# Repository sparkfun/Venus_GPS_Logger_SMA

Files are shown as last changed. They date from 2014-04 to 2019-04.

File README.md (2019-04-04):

**NOTE:** *This product has been retired from our catalog. If you are looking for more up-to-date info, please check out some of these resources to see how other users are still hacking and improving on this product.*
* *[SparkFun Forum](https://forum.sparkfun.com/)*
* *[Comments Here on GitHub](https://github.com/sparkfun/Venus_GPS_Logger_SMA/issues)*
* *[IRC Channel](https://www.sparkfun.com/news/263)*

SparkFun Venus GPS Logger - SMA Connector
=========================================

SparkFun Venus GPS Logger - SMA Connector

[*SparkFun Venus GPS Logger - SMA Connector (GPS-10920)*](https://www.sparkfun.com/products/10920)

This is a breakout board for the Venus638FLPx chip. It can be configured up to 20Hz update rate. This has an on-board JST connector for battery
power and an SMA connector for an antenna. This unit supports external SPI flash memory data logging, and has the 32M Serial Flash Memory IC.

Repository Contents
-------------------
* **/Hardware** - All Eagle design files (.brd, .sch)
* **/Production** - Test bed files and production panel files

Documentation
--------------
* **[SparkFun Fritzing repo](https://github.com/sparkfun/Fritzing_Parts)** - Fritzing diagrams for SparkFun products.
* **[SparkFun 3D Model repo](https://github.com/sparkfun/3D_Models)** - 3D models of SparkFun products. 

License Information
-------------------

This product is _**open source**_! 

Please review the LICENSE.md file for license information. 

If you have any questions or concerns on licensing, please contact techsupport@sparkfun.com.

Distributed as-is; no warranty is given.

- Your friends at SparkFun.

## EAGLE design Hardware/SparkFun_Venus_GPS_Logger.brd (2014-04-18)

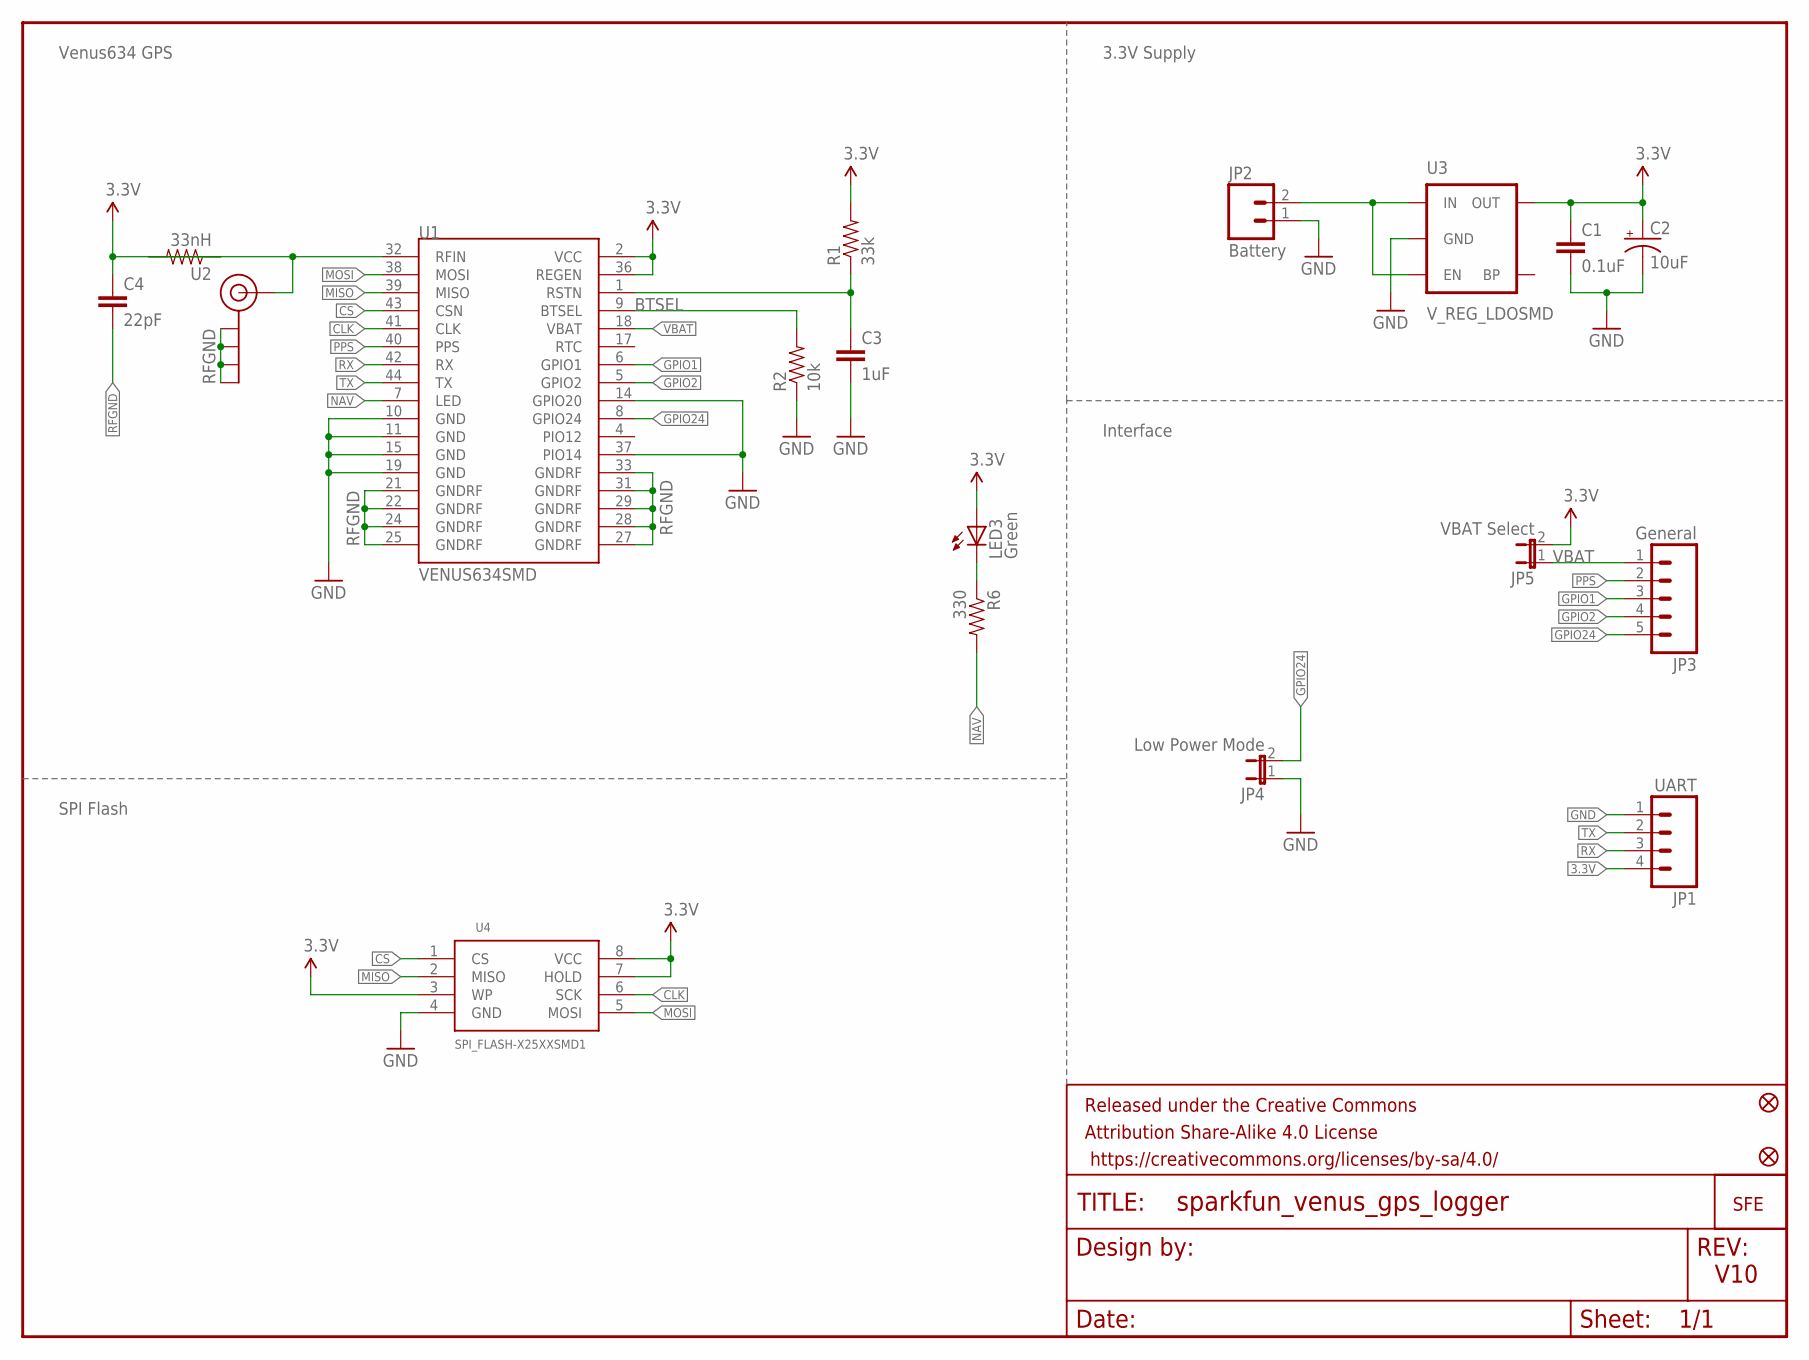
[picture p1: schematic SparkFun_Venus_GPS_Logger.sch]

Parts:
C1: 0.1uF; 0603-CAP
C2: 10uF; EIA3216
C3: 1uF; 0603-CAP
C4: 22pF; 0603-CAP
FID1, FID2: FIDUCIAL1X2; FIDUCIAL-1X2
FRAME1: FRAME-LETTER; CREATIVE_COMMONS
J$1: SMA_EDGE; SMA-EDGE
JP1: UART; 1X04
JP2: Battery; S2B-PH
JP3: General; 1X05
JP4: Low Power Mode; SJ_2S
JP5: VBAT Select; SJ_2S
LED3: Green; LED-0603
R1: 33k; 0603-RES
R2: 10k; 0603-RES
R6: 330; 0603-RES
U1: VENUS634SMD; LGA44
U2: 33nH; 0603-RES
U3: V_REG_LDOSMD; SOT23-5
U4: SPI_FLASH-X25XXSMD1; SO08-EIAJ
U$1: LOGO-SFESK; SFE-LOGO-FLAME

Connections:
3.3V: C1.1, C2.A (+), C4.1, JP1.4, JP5.2, LED3.A, R1.2, U1.2 (VCC), U1.36 (REGEN), U2.1, U3.5 (OUT), U4.3 (WP), U4.7 (HOLD), U4.8 (VCC)
BTSEL: R2.2, U1.9 (BTSEL)
CLK: U1.41 (CLK), U4.6 (SCK)
CS: U1.43 (CSN), U4.1 (CS)
GND: C1.2, C2.C (-), C3.2, JP1.1, JP2.1, JP4.1, R2.1, U1.10 (GND), U1.11 (GND), U1.14 (GPIO20), U1.15 (GND), U1.19 (GND), U1.37 (PIO14), U3.2 (GND), U4.4 (GND)
GPIO1: JP3.3, U1.6 (GPIO1)
GPIO2: JP3.4, U1.5 (GPIO2)
GPIO24: JP3.5, JP4.2, U1.8 (GPIO24)
MISO: U1.39 (MISO), U4.2 (MISO)
MOSI: U1.38 (MOSI), U4.5 (MOSI)
unnamed: LED3.C, R6.1
unnamed: C3.1, R1.1, U1.1 (RSTN)
unnamed: J$1.SIG (SIGNAL), U1.32 (RFIN), U2.2
NAV: R6.2, U1.7 (LED)
PPS: JP3.2, U1.40 (PPS)
RFGND: C4.2, J$1.GND@0 (GND), J$1.GND@1 (GND), J$1.GND@2 (GND), J$1.GND@3 (GND), U1.21 (GNDRF), U1.22 (GNDRF), U1.24 (GNDRF), U1.25 (GNDRF), U1.27 (GNDRF), U1.28 (GNDRF), U1.29 (GNDRF), U1.31 (GNDRF), U1.33 (GNDRF)
RX: JP1.3, U1.42 (RX)
TX: JP1.2, U1.44 (TX)
VBAT: JP3.1, JP5.1, U1.18 (VBAT)
VBATT: JP2.2, U3.1 (IN), U3.3 (EN)

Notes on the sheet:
SPI Flash
Venus634 GPS
3.3V Supply
Interface
V10

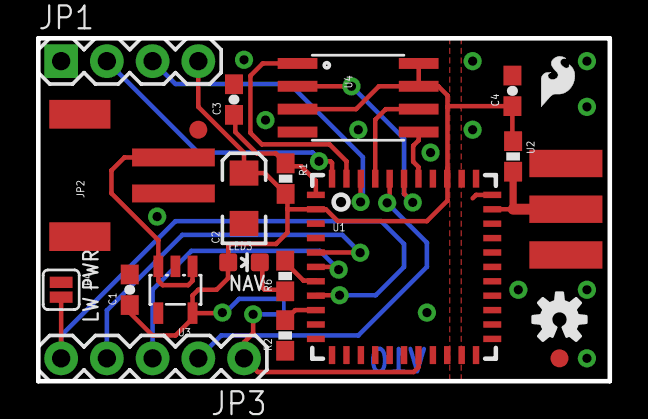
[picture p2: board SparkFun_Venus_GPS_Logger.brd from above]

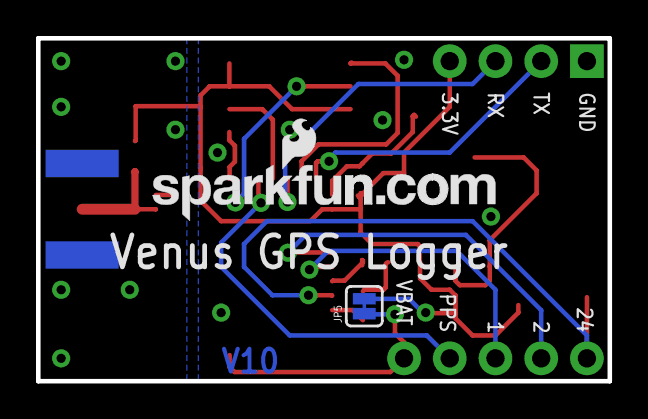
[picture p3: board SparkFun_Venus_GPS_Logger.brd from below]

Board: 2 copper layers, 31.8 x 19.1 mm, 24 parts (2 on the bottom side), 20 nets.

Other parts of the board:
U$2: OSHW-LOGO-S
U$3: SFE-NEW-WEBLOGO

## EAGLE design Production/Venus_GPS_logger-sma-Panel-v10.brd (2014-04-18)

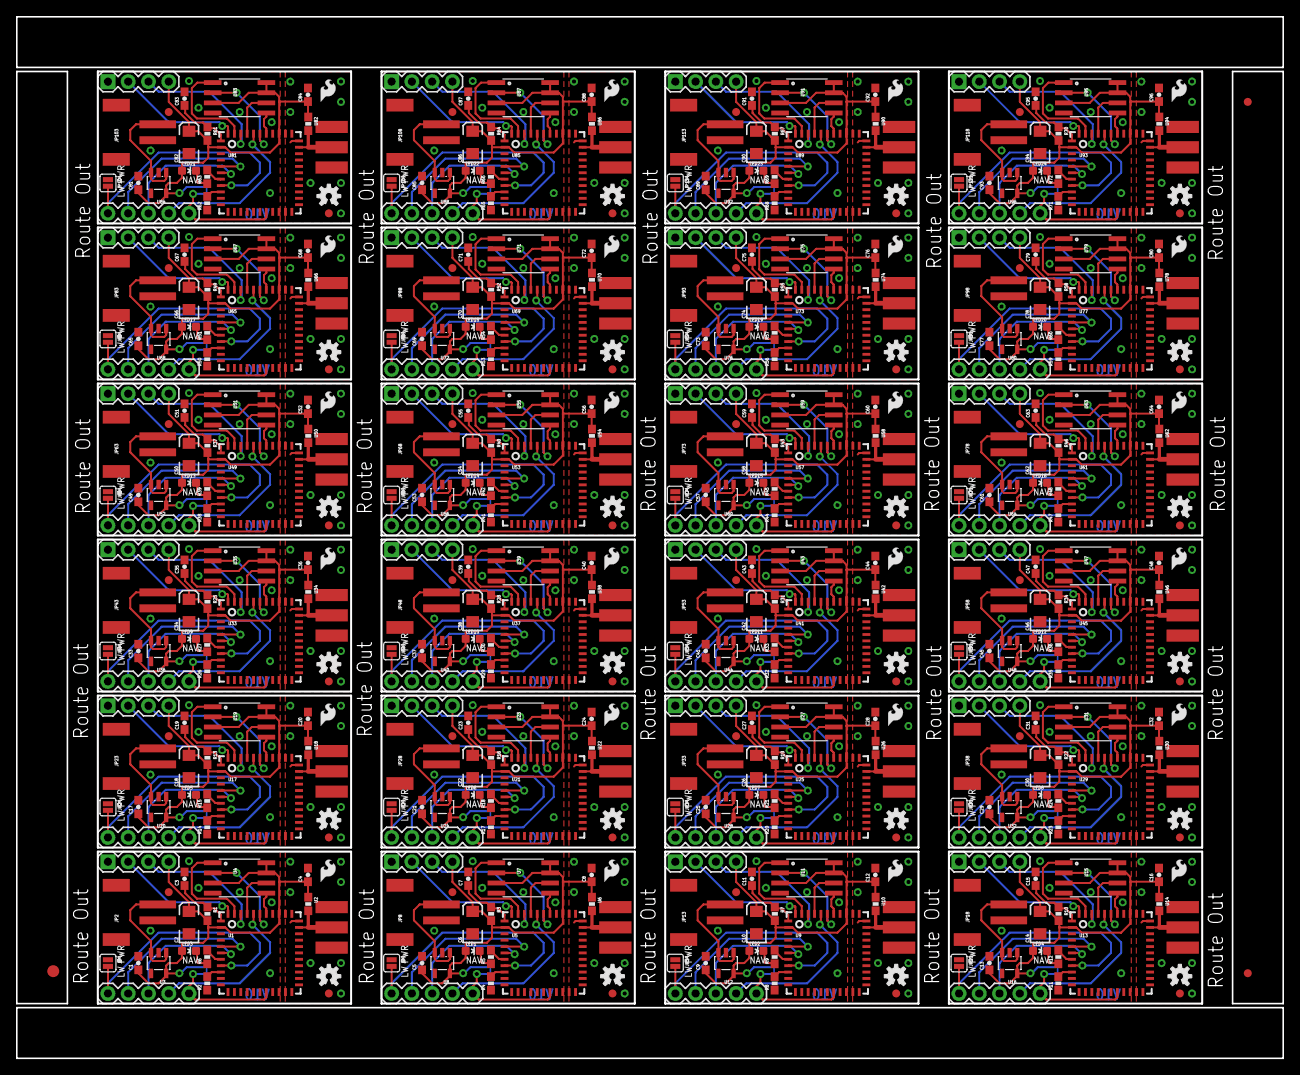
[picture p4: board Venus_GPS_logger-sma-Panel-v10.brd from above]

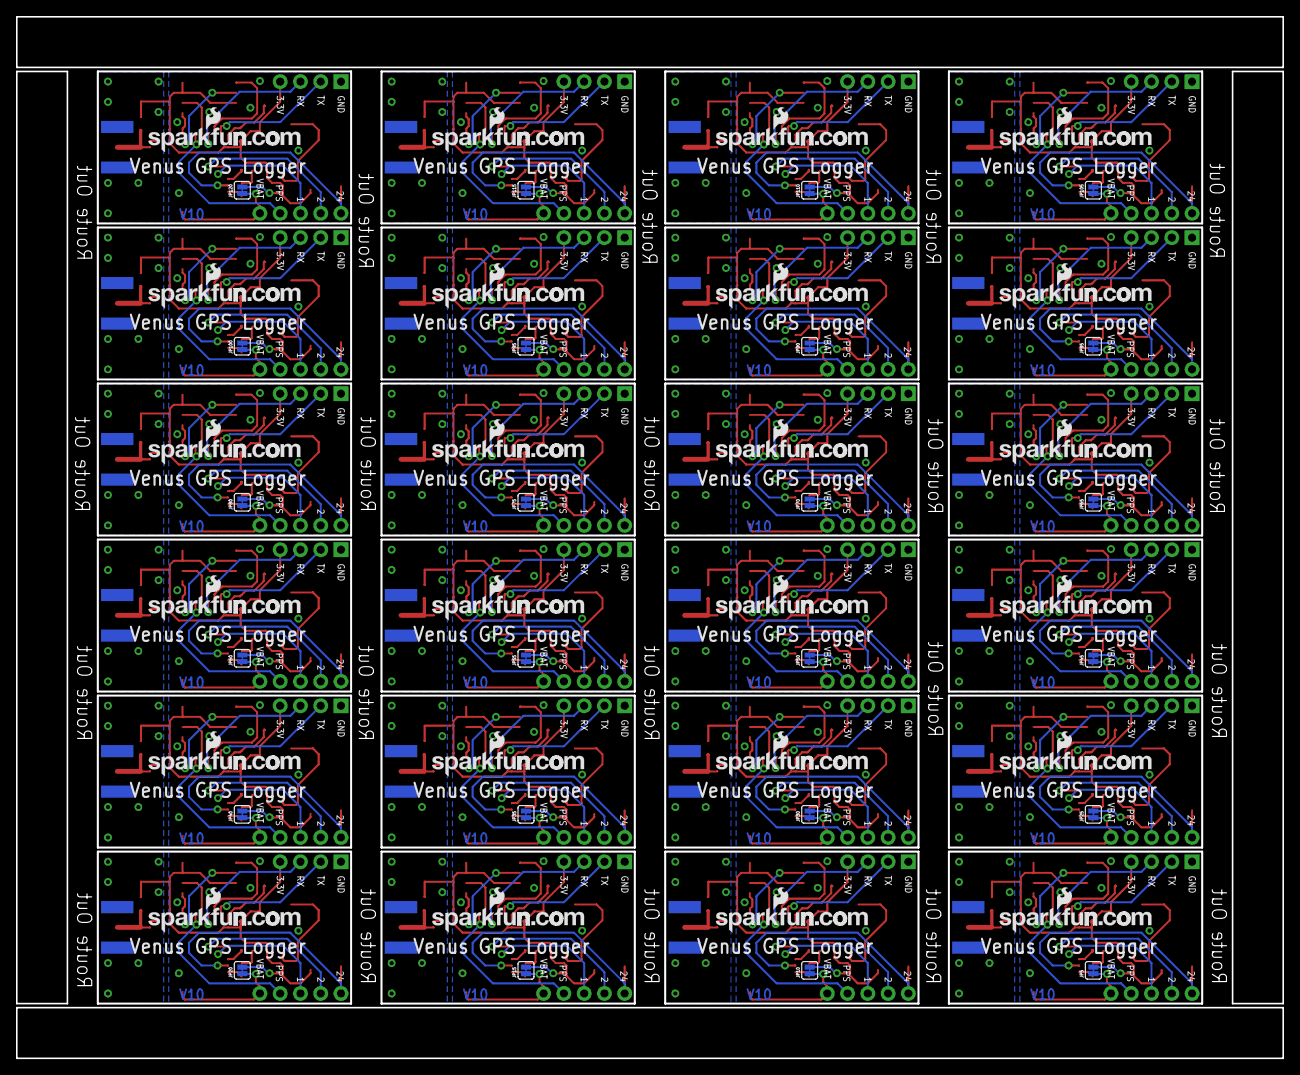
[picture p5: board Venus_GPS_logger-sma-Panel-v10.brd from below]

Board: 2 copper layers, 158.8 x 130.6 mm, 555 parts (48 on the bottom side), 480 nets.

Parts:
C1, C5, C9, C13, C17, C21, C25, C29, C33, C37, C41, C45, C49, C53, C57, C61, C65, C69, C73, C77, C81, C85, C89, C93: 0.1uF; 0603-CAP
C2, C6, C10, C14, C18, C22, C26, C30, C34, C38, C42, C46, C50, C54, C58, C62, C66, C70, C74, C78, C82, C86, C90, C94: 10uF; EIA3216
C3, C7, C11, C15, C19, C23, C27, C31, C35, C39, C43, C47, C51, C55, C59, C63, C67, C71, C75, C79, C83, C87, C91, C95: 1uF; 0603-CAP
C4, C8, C12, C16, C20, C24, C28, C32, C36, C40, C44, C48, C52, C56, C60, C64, C68, C72, C76, C80, C84, C88, C92, C96: 22pF; 0603-CAP
E$1: FIDUCIAL-1.5X3
E$3, E$4: FIDUCIAL-1X2
FID1, FID2, FID3, FID4, FID5, FID6, FID7, FID8, FID9, FID10, FID11, FID12, FID13, FID14, FID15, FID16, FID17, FID18, FID19, FID20, FID21, FID22, FID23, FID24, FID25, FID26, FID27, FID28, FID29, FID30, FID31, FID32, FID33, FID34, FID35, FID36, FID37, FID38, FID39, FID40, FID41, FID42, FID43, FID44, FID45, FID46, FID47, FID48: FIDUCIAL1X2; FIDUCIAL-1X2
J$1, J$2, J$3, J$4, J$5, J$6, J$7, J$8, J$9, J$10, J$11, J$12, J$13, J$14, J$15, J$16, J$17, J$18, J$19, J$20, J$21, J$22, J$23, J$24: SMA_EDGE; SMA-EDGE
JP1, JP6, JP11, JP16, JP21, JP26, JP31, JP36, JP41, JP46, JP51, JP56, JP61, JP66, JP71, JP76, JP81, JP86, JP91, JP96, JP101, JP106, JP111, JP116: UART; 1X04
JP2, JP8, JP13, JP18, JP23, JP28, JP33, JP38, JP43, JP48, JP53, JP58, JP63, JP68, JP73, JP78, JP83, JP88, JP93, JP98, JP103, JP108, JP113, JP118: Battery; S2B-PH
JP3, JP7, JP12, JP17, JP22, JP27, JP32, JP37, JP42, JP47, JP52, JP57, JP62, JP67, JP72, JP77, JP82, JP87, JP92, JP97, JP102, JP107, JP112, JP117: General; 1X05
JP4, JP9, JP14, JP19, JP24, JP29, JP34, JP39, JP44, JP49, JP54, JP59, JP64, JP69, JP74, JP79, JP84, JP89, JP94, JP99, JP104, JP109, JP114, JP119: Low Power Mode; SJ_2S
JP5, JP10, JP15, JP20, JP25, JP30, JP35, JP40, JP45, JP50, JP55, JP60, JP65, JP70, JP75, JP80, JP85, JP90, JP95, JP100, JP105, JP110, JP115, JP120: VBAT Select; SJ_2S
LED1, LED2, LED3, LED4, LED5, LED6, LED7, LED8, LED9, LED10, LED11, LED12, LED13, LED14, LED15, LED16, LED17, LED18, LED19, LED20, LED21, LED22, LED23, LED24: Green; LED-0603
R1, R3, R7, R10, R13, R16, R19, R22, R25, R28, R31, R34, R37, R40, R43, R46, R49, R52, R55, R58, R61, R64, R67, R70: 33k; 0603-RES
R2, R4, R8, R11, R14, R17, R20, R23, R26, R29, R32, R35, R38, R41, R44, R47, R50, R53, R56, R59, R62, R65, R68, R71: 10k; 0603-RES
R5, R6, R9, R12, R15, R18, R21, R24, R27, R30, R33, R36, R39, R42, R45, R48, R51, R54, R57, R60, R63, R66, R69, R72: 330; 0603-RES
U1, U5, U9, U13, U17, U21, U25, U29, U33, U37, U41, U45, U49, U53, U57, U61, U65, U69, U73, U77, U81, U85, U89, U93: VENUS634SMD; LGA44
U2, U6, U10, U14, U18, U22, U26, U30, U34, U38, U42, U46, U50, U54, U58, U62, U66, U70, U74, U78, U82, U86, U90, U94: 33nH; 0603-RES
U3, U8, U12, U16, U20, U24, U28, U32, U36, U40, U44, U48, U52, U56, U60, U64, U68, U72, U76, U80, U84, U88, U92, U96: V_REG_LDOSMD; SOT23-5
U4, U7, U11, U15, U19, U23, U27, U31, U35, U39, U43, U47, U51, U55, U59, U63, U67, U71, U75, U79, U83, U87, U91, U95: SPI_FLASH-X25XXSMD1; SO08-EIAJ
U$1, U$4, U$7, U$10, U$13, U$16, U$19, U$22, U$25, U$28, U$31, U$34, U$37, U$40, U$43, U$46, U$49, U$52, U$55, U$58, U$61, U$64, U$67, U$70: LOGO-SFESK; SFE-LOGO-FLAME
U$2, U$5, U$8, U$11, U$14, U$17, U$20, U$23, U$26, U$29, U$32, U$35, U$38, U$41, U$44, U$47, U$50, U$53, U$56, U$59, U$62, U$65, U$68, U$71: OSHW-LOGO-S
U$3, U$6, U$9, U$12, U$15, U$18, U$21, U$24, U$27, U$30, U$33, U$36, U$39, U$42, U$45, U$48, U$51, U$54, U$57, U$60, U$63, U$66, U$69, U$72: SFE-NEW-WEBLOGO

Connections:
3.3V: C1.1, C2.A, C4.1, JP1.4, JP5.2, LED3.A, R1.2, U1.2, U1.36, U2.1, U3.5, U4.3, U4.7, U4.8
3.3V1: C5.1, C6.A, C8.1, JP6.4, JP10.2, LED1.A, R3.2, U5.2, U5.36, U6.1, U7.3, U7.7, U7.8, U8.5
3.3V2: C9.1, C10.A, C12.1, JP11.4, JP15.2, LED2.A, R7.2, U9.2, U9.36, U10.1, U11.3, U11.7, U11.8, U12.5
3.3V3: C13.1, C14.A, C16.1, JP16.4, JP20.2, LED4.A, R10.2, U13.2, U13.36, U14.1, U15.3, U15.7, U15.8, U16.5
3.3V4: C17.1, C18.A, C20.1, JP21.4, JP25.2, LED5.A, R13.2, U17.2, U17.36, U18.1, U19.3, U19.7, U19.8, U20.5
3.3V5: C21.1, C22.A, C24.1, JP26.4, JP30.2, LED6.A, R16.2, U21.2, U21.36, U22.1, U23.3, U23.7, U23.8, U24.5
3.3V6: C25.1, C26.A, C28.1, JP31.4, JP35.2, LED7.A, R19.2, U25.2, U25.36, U26.1, U27.3, U27.7, U27.8, U28.5
3.3V7: C29.1, C30.A, C32.1, JP36.4, JP40.2, LED8.A, R22.2, U29.2, U29.36, U30.1, U31.3, U31.7, U31.8, U32.5
3.3V8: C33.1, C34.A, C36.1, JP41.4, JP45.2, LED9.A, R25.2, U33.2, U33.36, U34.1, U35.3, U35.7, U35.8, U36.5
3.3V9: C37.1, C38.A, C40.1, JP46.4, JP50.2, LED10.A, R28.2, U37.2, U37.36, U38.1, U39.3, U39.7, U39.8, U40.5
3.3V10: C41.1, C42.A, C44.1, JP51.4, JP55.2, LED11.A, R31.2, U41.2, U41.36, U42.1, U43.3, U43.7, U43.8, U44.5
3.3V11: C45.1, C46.A, C48.1, JP56.4, JP60.2, LED12.A, R34.2, U45.2, U45.36, U46.1, U47.3, U47.7, U47.8, U48.5
3.3V12: C49.1, C50.A, C52.1, JP61.4, JP65.2, LED13.A, R37.2, U49.2, U49.36, U50.1, U51.3, U51.7, U51.8, U52.5
3.3V13: C53.1, C54.A, C56.1, JP66.4, JP70.2, LED14.A, R40.2, U53.2, U53.36, U54.1, U55.3, U55.7, U55.8, U56.5
3.3V14: C57.1, C58.A, C60.1, JP71.4, JP75.2, LED15.A, R43.2, U57.2, U57.36, U58.1, U59.3, U59.7, U59.8, U60.5
3.3V15: C61.1, C62.A, C64.1, JP76.4, JP80.2, LED16.A, R46.2, U61.2, U61.36, U62.1, U63.3, U63.7, U63.8, U64.5
3.3V16: C65.1, C66.A, C68.1, JP81.4, JP85.2, LED17.A, R49.2, U65.2, U65.36, U66.1, U67.3, U67.7, U67.8, U68.5
3.3V17: C69.1, C70.A, C72.1, JP86.4, JP90.2, LED18.A, R52.2, U69.2, U69.36, U70.1, U71.3, U71.7, U71.8, U72.5
3.3V18: C73.1, C74.A, C76.1, JP91.4, JP95.2, LED19.A, R55.2, U73.2, U73.36, U74.1, U75.3, U75.7, U75.8, U76.5
3.3V19: C77.1, C78.A, C80.1, JP96.4, JP100.2, LED20.A, R58.2, U77.2, U77.36, U78.1, U79.3, U79.7, U79.8, U80.5
3.3V20: C81.1, C82.A, C84.1, JP101.4, JP105.2, LED21.A, R61.2, U81.2, U81.36, U82.1, U83.3, U83.7, U83.8, U84.5
3.3V21: C85.1, C86.A, C88.1, JP106.4, JP110.2, LED22.A, R64.2, U85.2, U85.36, U86.1, U87.3, U87.7, U87.8, U88.5
3.3V22: C89.1, C90.A, C92.1, JP111.4, JP115.2, LED23.A, R67.2, U89.2, U89.36, U90.1, U91.3, U91.7, U91.8, U92.5
3.3V23: C93.1, C94.A, C96.1, JP116.4, JP120.2, LED24.A, R70.2, U93.2, U93.36, U94.1, U95.3, U95.7, U95.8, U96.5
BTSEL: R2.2, U1.9
BTSEL1: R4.2, U5.9
BTSEL2: R8.2, U9.9
BTSEL3: R11.2, U13.9
BTSEL4: R14.2, U17.9
BTSEL5: R17.2, U21.9
BTSEL6: R20.2, U25.9
BTSEL7: R23.2, U29.9
BTSEL8: R26.2, U33.9
BTSEL9: R29.2, U37.9
BTSEL10: R32.2, U41.9
BTSEL11: R35.2, U45.9
BTSEL12: R38.2, U49.9
BTSEL13: R41.2, U53.9
BTSEL14: R44.2, U57.9
BTSEL15: R47.2, U61.9
BTSEL16: R50.2, U65.9
BTSEL17: R53.2, U69.9
BTSEL18: R56.2, U73.9
BTSEL19: R59.2, U77.9
BTSEL20: R62.2, U81.9
BTSEL21: R65.2, U85.9
BTSEL22: R68.2, U89.9
BTSEL23: R71.2, U93.9
CLK: U1.41, U4.6
CLK1: U5.41, U7.6
CLK2: U9.41, U11.6
CLK3: U13.41, U15.6
CLK4: U17.41, U19.6
CLK5: U21.41, U23.6
CLK6: U25.41, U27.6
CLK7: U29.41, U31.6
CLK8: U33.41, U35.6
CLK9: U37.41, U39.6
CLK10: U41.41, U43.6
CLK11: U45.41, U47.6
CLK12: U49.41, U51.6
CLK13: U53.41, U55.6
CLK14: U57.41, U59.6
CLK15: U61.41, U63.6
CLK16: U65.41, U67.6
CLK17: U69.41, U71.6
CLK18: U73.41, U75.6
CLK19: U77.41, U79.6
CLK20: U81.41, U83.6
CLK21: U85.41, U87.6
CLK22: U89.41, U91.6
CLK23: U93.41, U95.6
CS: U1.43, U4.1
CS1: U5.43, U7.1
CS2: U9.43, U11.1
CS3: U13.43, U15.1
CS4: U17.43, U19.1
CS5: U21.43, U23.1
CS6: U25.43, U27.1
CS7: U29.43, U31.1
CS8: U33.43, U35.1
CS9: U37.43, U39.1
CS10: U41.43, U43.1
CS11: U45.43, U47.1
CS12: U49.43, U51.1
CS13: U53.43, U55.1
CS14: U57.43, U59.1
CS15: U61.43, U63.1
CS16: U65.43, U67.1
CS17: U69.43, U71.1
CS18: U73.43, U75.1
CS19: U77.43, U79.1
CS20: U81.43, U83.1
CS21: U85.43, U87.1
CS22: U89.43, U91.1
CS23: U93.43, U95.1
GND: C1.2, C2.C, C3.2, JP1.1, JP2.1, JP4.1, R2.1, U1.10, U1.11, U1.14, U1.15, U1.19, U1.37, U3.2, U4.4
GND1: C5.2, C6.C, C7.2, JP6.1, JP8.1, JP9.1, R4.1, U5.10, U5.11, U5.14, U5.15, U5.19, U5.37, U7.4, U8.2
GND2: C9.2, C10.C, C11.2, JP11.1, JP13.1, JP14.1, R8.1, U9.10, U9.11, U9.14, U9.15, U9.19, U9.37, U11.4, U12.2
GND3: C13.2, C14.C, C15.2, JP16.1, JP18.1, JP19.1, R11.1, U13.10, U13.11, U13.14, U13.15, U13.19, U13.37, U15.4, U16.2
GND4: C17.2, C18.C, C19.2, JP21.1, JP23.1, JP24.1, R14.1, U17.10, U17.11, U17.14, U17.15, U17.19, U17.37, U19.4, U20.2
GND5: C21.2, C22.C, C23.2, JP26.1, JP28.1, JP29.1, R17.1, U21.10, U21.11, U21.14, U21.15, U21.19, U21.37, U23.4, U24.2
GND6: C25.2, C26.C, C27.2, JP31.1, JP33.1, JP34.1, R20.1, U25.10, U25.11, U25.14, U25.15, U25.19, U25.37, U27.4, U28.2
GND7: C29.2, C30.C, C31.2, JP36.1, JP38.1, JP39.1, R23.1, U29.10, U29.11, U29.14, U29.15, U29.19, U29.37, U31.4, U32.2
GND8: C33.2, C34.C, C35.2, JP41.1, JP43.1, JP44.1, R26.1, U33.10, U33.11, U33.14, U33.15, U33.19, U33.37, U35.4, U36.2
GND9: C37.2, C38.C, C39.2, JP46.1, JP48.1, JP49.1, R29.1, U37.10, U37.11, U37.14, U37.15, U37.19, U37.37, U39.4, U40.2
GND10: C41.2, C42.C, C43.2, JP51.1, JP53.1, JP54.1, R32.1, U41.10, U41.11, U41.14, U41.15, U41.19, U41.37, U43.4, U44.2
GND11: C45.2, C46.C, C47.2, JP56.1, JP58.1, JP59.1, R35.1, U45.10, U45.11, U45.14, U45.15, U45.19, U45.37, U47.4, U48.2
GND12: C49.2, C50.C, C51.2, JP61.1, JP63.1, JP64.1, R38.1, U49.10, U49.11, U49.14, U49.15, U49.19, U49.37, U51.4, U52.2
GND13: C53.2, C54.C, C55.2, JP66.1, JP68.1, JP69.1, R41.1, U53.10, U53.11, U53.14, U53.15, U53.19, U53.37, U55.4, U56.2
GND14: C57.2, C58.C, C59.2, JP71.1, JP73.1, JP74.1, R44.1, U57.10, U57.11, U57.14, U57.15, U57.19, U57.37, U59.4, U60.2
GND15: C61.2, C62.C, C63.2, JP76.1, JP78.1, JP79.1, R47.1, U61.10, U61.11, U61.14, U61.15, U61.19, U61.37, U63.4, U64.2
GND16: C65.2, C66.C, C67.2, JP81.1, JP83.1, JP84.1, R50.1, U65.10, U65.11, U65.14, U65.15, U65.19, U65.37, U67.4, U68.2
GND17: C69.2, C70.C, C71.2, JP86.1, JP88.1, JP89.1, R53.1, U69.10, U69.11, U69.14, U69.15, U69.19, U69.37, U71.4, U72.2
GND18: C73.2, C74.C, C75.2, JP91.1, JP93.1, JP94.1, R56.1, U73.10, U73.11, U73.14, U73.15, U73.19, U73.37, U75.4, U76.2
GND19: C77.2, C78.C, C79.2, JP96.1, JP98.1, JP99.1, R59.1, U77.10, U77.11, U77.14, U77.15, U77.19, U77.37, U79.4, U80.2
GND20: C81.2, C82.C, C83.2, JP101.1, JP103.1, JP104.1, R62.1, U81.10, U81.11, U81.14, U81.15, U81.19, U81.37, U83.4, U84.2
GND21: C85.2, C86.C, C87.2, JP106.1, JP108.1, JP109.1, R65.1, U85.10, U85.11, U85.14, U85.15, U85.19, U85.37, U87.4, U88.2
GND22: C89.2, C90.C, C91.2, JP111.1, JP113.1, JP114.1, R68.1, U89.10, U89.11, U89.14, U89.15, U89.19, U89.37, U91.4, U92.2
GND23: C93.2, C94.C, C95.2, JP116.1, JP118.1, JP119.1, R71.1, U93.10, U93.11, U93.14, U93.15, U93.19, U93.37, U95.4, U96.2
GPIO1: JP3.3, U1.6
GPIO2: JP3.4, U1.5
GPIO3: JP7.3, U5.6
GPIO4: JP7.4, U5.5
GPIO5: JP7.5, JP9.2, U5.8
GPIO6: JP12.3, U9.6
GPIO7: JP12.4, U9.5
GPIO8: JP12.5, JP14.2, U9.8
GPIO9: JP17.3, U13.6
GPIO10: JP17.4, U13.5
GPIO11: JP17.5, JP19.2, U13.8
GPIO12: JP22.3, U17.6
GPIO13: JP22.4, U17.5
GPIO14: JP22.5, JP24.2, U17.8
GPIO15: JP27.3, U21.6
GPIO16: JP27.4, U21.5
GPIO17: JP27.5, JP29.2, U21.8
GPIO18: JP32.3, U25.6
GPIO19: JP32.4, U25.5
GPIO20: JP32.5, JP34.2, U25.8
GPIO21: JP37.3, U29.6
GPIO22: JP37.4, U29.5
GPIO23: JP37.5, JP39.2, U29.8
GPIO24: JP3.5, JP4.2, U1.8
GPIO25: JP42.3, U33.6
GPIO26: JP42.4, U33.5
GPIO27: JP42.5, JP44.2, U33.8
GPIO28: JP47.3, U37.6
GPIO29: JP47.4, U37.5
GPIO30: JP47.5, JP49.2, U37.8
GPIO31: JP52.3, U41.6
GPIO32: JP52.4, U41.5
GPIO33: JP52.5, JP54.2, U41.8
GPIO34: JP57.3, U45.6
GPIO35: JP57.4, U45.5
GPIO36: JP57.5, JP59.2, U45.8
GPIO37: JP62.3, U49.6
GPIO38: JP62.4, U49.5
GPIO39: JP62.5, JP64.2, U49.8
GPIO40: JP67.3, U53.6
GPIO41: JP67.4, U53.5
GPIO42: JP67.5, JP69.2, U53.8
GPIO43: JP72.3, U57.6
GPIO44: JP72.4, U57.5
GPIO45: JP72.5, JP74.2, U57.8
GPIO46: JP77.3, U61.6
GPIO47: JP77.4, U61.5
GPIO48: JP77.5, JP79.2, U61.8
GPIO49: JP82.3, U65.6
GPIO50: JP82.4, U65.5
GPIO51: JP82.5, JP84.2, U65.8
GPIO52: JP87.3, U69.6
GPIO53: JP87.4, U69.5
GPIO54: JP87.5, JP89.2, U69.8
GPIO55: JP92.3, U73.6
GPIO56: JP92.4, U73.5
GPIO57: JP92.5, JP94.2, U73.8
GPIO58: JP97.3, U77.6
GPIO59: JP97.4, U77.5
GPIO60: JP97.5, JP99.2, U77.8
GPIO61: JP102.3, U81.6
GPIO62: JP102.4, U81.5
GPIO63: JP102.5, JP104.2, U81.8
GPIO64: JP107.3, U85.6
GPIO65: JP107.4, U85.5
GPIO66: JP107.5, JP109.2, U85.8
GPIO67: JP112.3, U89.6
GPIO68: JP112.4, U89.5
GPIO69: JP112.5, JP114.2, U89.8
GPIO70: JP117.3, U93.6
GPIO71: JP117.4, U93.5
GPIO72: JP117.5, JP119.2, U93.8
MISO: U1.39, U4.2
MISO1: U5.39, U7.2
MISO2: U9.39, U11.2
MISO3: U13.39, U15.2
MISO4: U17.39, U19.2
MISO5: U21.39, U23.2
MISO6: U25.39, U27.2
MISO7: U29.39, U31.2
MISO8: U33.39, U35.2
MISO9: U37.39, U39.2
MISO10: U41.39, U43.2
MISO11: U45.39, U47.2
MISO12: U49.39, U51.2
MISO13: U53.39, U55.2
MISO14: U57.39, U59.2
MISO15: U61.39, U63.2
MISO16: U65.39, U67.2
MISO17: U69.39, U71.2
MISO18: U73.39, U75.2
MISO19: U77.39, U79.2
MISO20: U81.39, U83.2
MISO21: U85.39, U87.2
MISO22: U89.39, U91.2
MISO23: U93.39, U95.2
MOSI: U1.38, U4.5
MOSI1: U5.38, U7.5
MOSI2: U9.38, U11.5
MOSI3: U13.38, U15.5
MOSI4: U17.38, U19.5
MOSI5: U21.38, U23.5
MOSI6: U25.38, U27.5
MOSI7: U29.38, U31.5
MOSI8: U33.38, U35.5
MOSI9: U37.38, U39.5
MOSI10: U41.38, U43.5
MOSI11: U45.38, U47.5
MOSI12: U49.38, U51.5
MOSI13: U53.38, U55.5
MOSI14: U57.38, U59.5
MOSI15: U61.38, U63.5
MOSI16: U65.38, U67.5
MOSI17: U69.38, U71.5
MOSI18: U73.38, U75.5
MOSI19: U77.38, U79.5
MOSI20: U81.38, U83.5
MOSI21: U85.38, U87.5
MOSI22: U89.38, U91.5
MOSI23: U93.38, U95.5
unnamed: LED3.C, R6.1
unnamed: J$2.SIG, U5.32, U6.2
unnamed: C3.1, R1.1, U1.1
unnamed: LED1.C, R5.1
unnamed: C7.1, R3.1, U5.1
unnamed: J$3.SIG, U9.32, U10.2
unnamed: LED2.C, R9.1
unnamed: C11.1, R7.1, U9.1
unnamed: J$4.SIG, U13.32, U14.2
unnamed: LED4.C, R12.1
unnamed: J$1.SIG, U1.32, U2.2
unnamed: C15.1, R10.1, U13.1
unnamed: J$5.SIG, U17.32, U18.2
unnamed: LED5.C, R15.1
unnamed: C19.1, R13.1, U17.1
unnamed: J$6.SIG, U21.32, U22.2
unnamed: LED6.C, R18.1
unnamed: C23.1, R16.1, U21.1
unnamed: J$7.SIG, U25.32, U26.2
unnamed: LED7.C, R21.1
unnamed: C27.1, R19.1, U25.1
unnamed: J$8.SIG, U29.32, U30.2
unnamed: LED8.C, R24.1
unnamed: C31.1, R22.1, U29.1
unnamed: J$9.SIG, U33.32, U34.2
unnamed: LED9.C, R27.1
unnamed: C35.1, R25.1, U33.1
unnamed: J$10.SIG, U37.32, U38.2
unnamed: LED10.C, R30.1
unnamed: C39.1, R28.1, U37.1
unnamed: J$11.SIG, U41.32, U42.2
unnamed: LED11.C, R33.1
unnamed: C43.1, R31.1, U41.1
unnamed: J$12.SIG, U45.32, U46.2
unnamed: LED12.C, R36.1
unnamed: C47.1, R34.1, U45.1
unnamed: J$13.SIG, U49.32, U50.2
unnamed: LED13.C, R39.1
unnamed: C51.1, R37.1, U49.1
unnamed: J$14.SIG, U53.32, U54.2
unnamed: LED14.C, R42.1
unnamed: C55.1, R40.1, U53.1
unnamed: J$15.SIG, U57.32, U58.2
unnamed: LED15.C, R45.1
unnamed: C59.1, R43.1, U57.1
unnamed: J$16.SIG, U61.32, U62.2
unnamed: LED16.C, R48.1
unnamed: C63.1, R46.1, U61.1
unnamed: J$17.SIG, U65.32, U66.2
unnamed: LED17.C, R51.1
unnamed: C67.1, R49.1, U65.1
unnamed: J$18.SIG, U69.32, U70.2
unnamed: LED18.C, R54.1
unnamed: C71.1, R52.1, U69.1
unnamed: J$19.SIG, U73.32, U74.2
unnamed: LED19.C, R57.1
unnamed: C75.1, R55.1, U73.1
unnamed: J$20.SIG, U77.32, U78.2
unnamed: LED20.C, R60.1
unnamed: C79.1, R58.1, U77.1
unnamed: J$21.SIG, U81.32, U82.2
unnamed: LED21.C, R63.1
unnamed: C83.1, R61.1, U81.1
unnamed: J$22.SIG, U85.32, U86.2
unnamed: LED22.C, R66.1
unnamed: C87.1, R64.1, U85.1
unnamed: J$23.SIG, U89.32, U90.2
unnamed: LED23.C, R69.1
unnamed: C91.1, R67.1, U89.1
unnamed: J$24.SIG, U93.32, U94.2
unnamed: LED24.C, R72.1
unnamed: C95.1, R70.1, U93.1
NAV: R6.2, U1.7
NAV1: R5.2, U5.7
NAV2: R9.2, U9.7
NAV3: R12.2, U13.7
NAV4: R15.2, U17.7
NAV5: R18.2, U21.7
NAV6: R21.2, U25.7
NAV7: R24.2, U29.7
NAV8: R27.2, U33.7
NAV9: R30.2, U37.7
NAV10: R33.2, U41.7
NAV11: R36.2, U45.7
NAV12: R39.2, U49.7
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

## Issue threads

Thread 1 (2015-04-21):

Checklist review v10 (post reds order)

lewispg228, 2015-04-21:
1) Is there a SparkFun Logo? [NO]
comment: sparkfun logo needs to be updated so it uses the logo graphic (not just the letters 'SFE')

2) Is there an OSHW logo? [NO]
comment: no OSHW in sch

3) Is proper attribution given to the original designer? [NO]
comment: needs designer

4) Is 'Revised by:' and 'reviser name' included? [NO]
comment: needs revised by and revisor

5) Have all nets been drawn straight out from pin connections at least one grid space? [NO]
comment: RF GND off of the antennae needs some space

6) Is the VCC range clearly labeled? [NO]
comment: needs vcc range in sch

7) Are any jumpers labeled clearly by their function and possible settings? [NO]
comment: could use a note saying 'close jumper to enter low power mode'

8) Does every part have a NAME and VALUE (with proper prefix and no '$')? [NO]
comment: U2 should be a L, and it needs to be rotated 180, the nets are overlapping, JP4 and JP5 should be an SJ - also needs to be updated to new jumper device

9) Does every part have a PROD_ID? [NO]
comment: check your prod ids, theres a few missing

10) Do any parts have unnecessary values (Eagle has autoset the package as the value)? [YES]
comment: U3

11) Is the LED color standard followed? (red for power, blue for STAT, green for TX, yellow for RX) [NO]
comment: LED should be blue

12) Are measurements included for outer dimension and standoffs (Eagle layer 47)? [NO]
comment: needs measures

13) Is the designer name included in tDocu? [NO]
comment: needs designer name

14) Is 'Revised by:' and 'Revisor Name' included in tDocu? [NO]
comment: needs this

Closed 2015-07-02.

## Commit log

2014-03-04 intial commit
    complete with BRD/SCH
    [Venus_GPS_Sma.brd, Venus_GPS_Sma.sch]
2014-03-05 Wrong BRD/SCH
    the wrong files were uploaded, uploading new files.
    [Venus_GPS_Sma.brd, Venus_GPS_Sma.sch, Venus_GPS_logger-sma.brd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]
2014-03-05 Updated caps/res/headers/jumpers
    upgraded to 0603 for all caps and res
    new tighter jumpers
    trace re routes
    added oshw logo
    added version #
    updated headers to have wider annular rings.
    [Venus_GPS_logger-sma.brd, Venus_GPS_logger-sma.sch]
2014-03-07 Updated LED, fixed questionable trace routes
    [Venus_GPS_logger-sma.brd, Venus_GPS_logger-sma.sch]
2014-03-18 Moved Jumper
    Moved jumper to the bttm copper, and changed silk on the jpm to "low
    power".
    [Venus_GPS_logger-sma.brd]
2014-03-18 Closed jumper
    [Venus_GPS_logger-sma.brd]
2014-04-18 changed fiducials to regular size and repositioned
    [Venus_GPS_logger-sma.brd, Venus_GPS_logger-sma.sch]
2014-04-18 created panel
    [Venus_GPS_logger-sma-Panel-v10.brd]
2014-08-07 Updating to original Eagle files
    [Venus_GPS_Flash-v11sma.brd, Venus_GPS_Flash-v11sma.sch, Venus_GPS_logger-sma-Panel-v10.brd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]
2014-08-07 Adding back in new revision files
    [Venus_GPS_Flash-v11sma.brd, Venus_GPS_Flash-v11sma.sch, Venus_GPS_logger-sma-Panel-v10.brd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]
2015-12-02 Updating README with new product info, fixing file names ;
    [SparkFun_Venus_GPS_Logger.brd, SparkFun_Venus_GPS_Logger.sch, Venus_GPS_logger-sma-Panel-v10.brd]

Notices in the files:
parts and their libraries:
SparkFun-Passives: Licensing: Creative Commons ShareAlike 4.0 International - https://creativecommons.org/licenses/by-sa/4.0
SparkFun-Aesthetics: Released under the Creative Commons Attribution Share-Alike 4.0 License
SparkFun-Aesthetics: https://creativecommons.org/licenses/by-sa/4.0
